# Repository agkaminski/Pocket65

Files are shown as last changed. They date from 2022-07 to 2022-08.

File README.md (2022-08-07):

# Pocket65

Handheld PC based on the original 6502 CPU that fits into a pocket.

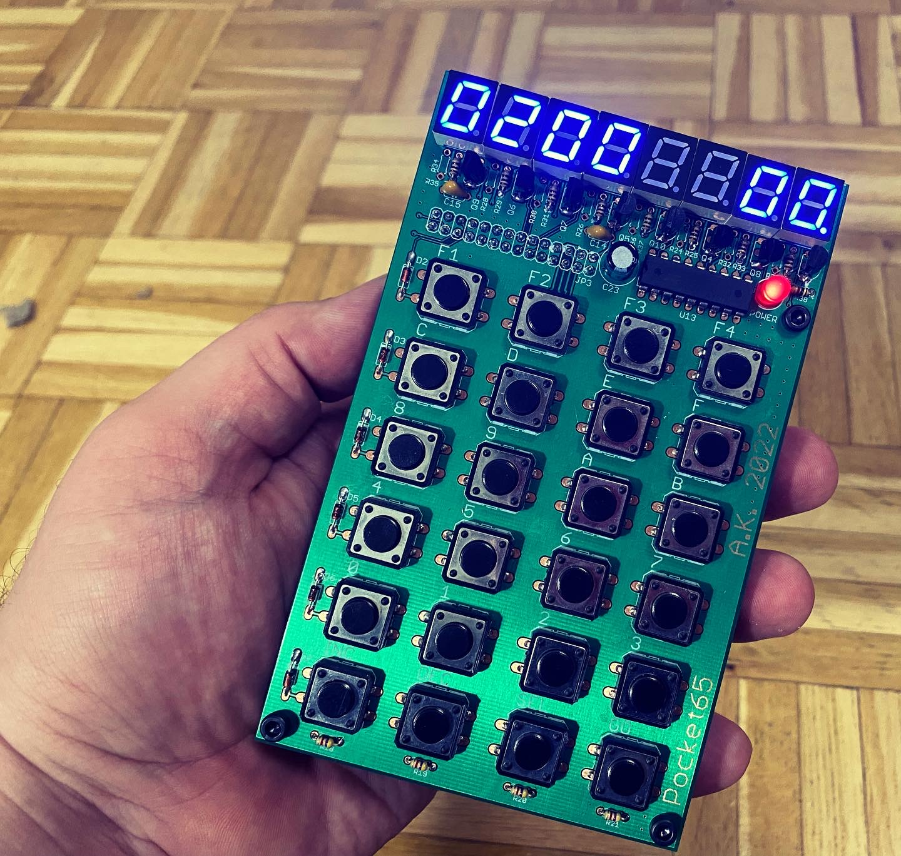
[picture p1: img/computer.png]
computer


## Features

- 8 digit multiplexed 7-segment display,
- 24 button keyboard,
- 2 KB of ROM and 2 KB of RAM,
- built-in Li-Po power supply and charger,
- monitor FW that allows memory edit and running user programs,
- expansion slot with 3 chip selects (up to 24 KB of external I/O and/or memory).

# Memory map

| Start  | End | Description |
|---|---|---|
| 0x0000 | 0x07FF | RAM |
| 0x0800 | 0x1FFF | RAM aliased |
| 0x2000 | 0x3FFF | External 1  |
| 0x4000 | 0x5FFF | External 2  |
| 0x6000 | 0x7FFF | External 3  |
| 0x8000 | 0x9FFF | Screen |
| 0xA000 | 0xBFFF | Keyboard |
| 0xC000 | 0xDFFF | NMI ack |
| 0xE000 | 0xF7FF | ROM aliased |
| 0xF800 | 0xFFFF | ROM |

# Monitor how-to

## Startup

First, welcome splash-screen is displayed:

welcome screen

After one second memory test result is displayed:

memory test result

On the right is a decimal number of RAM bytes found. By default it's 2048 bytes, memory can be expanded using expansion slot. If an error occurs during memory test, error screen is presented and the system is halted:

memory test fail

After 2 seconds computer proceeds to the main mode of operation:

monitor

## Memory edit

In the main mode and byte modification selected (dot near memory value) memory modification is possible. To modify memory press a key `0` to `F`. The old value is then shifted 4 binary places to the left and new nibble is inserted at the youngest position. Previous 4 oldest bits are lost.

Example - entering `0xBA` at current address:

We start with our memory cell selected (in this case at the address `0x0200`):

memory edit start

press `B` button to enter 0xB:

b pressed

then press `A` button to finish entering the byte:

a pressed

Done!

## Address selection

The address can be modified in two ways:

### INC/DEC buttons

To select next/prev memory cell press `INC`/`DEC` button. The address will be incremented/decremented by one.

### Entering new address

Big leaps through memory space are not very convenient using incrementation/decrementation. You can change the address very similar to changing memory value. To enter address edit mode pres `SEL` key. Dot will appear next to address to confirm mode selection:

address edit mode

In this mode address can be modified the same way memory value is performed - when key `0-F` is pressed the old address is shifted 4 bits to the left and new value is inserted at the youngest position.

To exit address edit mode (and return to the memory value edit mode) press `SEL` key.

## Executing user program

To start user program provides its entry point in the address field and press `GO` button.

## F1 key - auto increment mode

`F1` key toggles auto-increment mode. When on it's indicated by dots enabled next to both address and value:

autoincrement mode

When this mode is active when the whole byte is entered (i.e. two key `0-F` presses) address will be incremented automatically. This mode is very useful for binary program listing input, as no additional key press between bytes is needed.

## F2 key - memory clear

`F2` key clears user memory - sets it to all zeroes. Memory locations from `0x0000` to `0x000CF` and from `0x2000` to RAM end are cleared.

## F3 key - memory copy

`F3` key copies _length_ bytes from _source_ to _destination_. _Destination_ is selected as the current address. After pressing `F3` user is prompted for source address:

memcpy source

selection is confirmed with `GO` key. After that user is prompted for _length_:

memcpy length

selection is again confirmed with `GO` key. Memory is then copied and computer returns to the main screen.

## F4 key - jump to the external ROM

`F4` key allows for quick enter to the external ROM placed at address `0x6000` (external chip select #3). To detect if the external ROM is present monitor checks for a magic value at address `0x6000`. Expected value is `0x4B41` (little-endian). If this check is successful jump to external ROM at address `0x6002` is performed. Otherwise an error message is displayed:

error

# Programming

User program examples are provided in `fw/example` directory, along with user program template, BIOS calls user library and Makefile.

User is free to use all memory, exluding:

| Start  | End | Description |
|---|---|---|
| 0x00D0 | 0x00FF | ROM ZP area |
| 0x0100 | 0x01FF | HW stack |
| 0x8000 | 0xDFFF | HW handled by ROM |

## Interrupts

Interrupt vectors are located in ROM area, so they cannot be changed by application code. Monitor can handle user IRQ and NMI handlers - there are two system calls to register user interrupt handler

- `svc_irq_register` register the IRQ handler,
- `svc_nmi_register` register the NMI handler.

The handler address is passed in X (low byte) and Y (high byte) registers.

Use `RTS` instruction to return from the handler insted of `RTI` - monitor handles return from the interrupt part.

## System calls

### Convention

When X, Y registers are used to pass 16-bit value, X holds low byte and Y holds high byte.

### `svc_reset`

Perform warm reset.

- Arguments: none.
- Returns: none.
- Destroys: N/A.

### `svc_irq_register`

Register user IRQ handler and enables interrupts.

- Arguments: X, Y - handler address.
- Returns: none.
- Destroys: A.

### `svc_nmi_register`

Register user NMI handler.

- Arguments: X, Y - handler address.
- Returns: none.
- Destroys: A.

### `svc_get_screen_ptr`

Return a pointer to the screen frame buffer to allow direct screen manipulation.

- Arguments: nome.
- Returns: X, Y - address.
- Destroys: none.

### `svc_putch`

Displays hex character on the screen on position X.

- Arguments: A - character, X - position
- Returns: none.
- Destroys: Y.

### `svc_putbyte`

Display a hex byte on the screen on position X. X is incremented to point on the next free screen posion.

- Arguments: A - byte, X - position
- Returns: none.
- Destroys: none.

### `svc_dot_enable`

Enable dot on the position X.

- Arguments: X - position
- Returns: none.
- Destroys: A.

### `svc_dot_disable`

Disable dot on the position X.

- Arguments: X - position
- Returns: none.
- Destroys: A.

### `svc_clear_screen`

Clear screen.

- Arguments: none.
- Returns: none.
- Destroys: A, X.

### `svc_prinx_u16`

Print 16-bit number in registers X, Y as hexadecimal number justified to the right.

- Arguments: X, Y - number.
- Returns: none.
- Destroys: A, X.

### `svc_prind_u16`

Print 16-bit number in registers X, Y as unsigned decimal number justified to the right.

- Arguments: X, Y - number.
- Returns: none.
- Destroys: A, X, Y.

### `svc_prind_s16`

Print 16-bit number in registers X, Y as signed decimal number justified to the right.

- Arguments: X, Y - number.
- Returns: none.
- Destroys: A, X, Y.

### `svc_prind_s16`

Print NULL terminated decoded 7 segment string from position A.

- Arguments: X, Y - pointer to the string, A - position on the screen.
- Returns: none.
- Destroys: A, X, Y.

### `svc_scanx_u16`

Get 16-bit unsigned number from the user (hexadecimal input).

- Arguments: none.
- Returns: X, Y - number.
- Destroys: A, X, Y.

### `svc_scand_u16`

Get 16-bit unsigned number from the user (decimal input).

- Arguments: none.
- Returns: X, Y - number.
- Destroys: A, X, Y.

### `svc_get_key`

Get key code - block until new key is pressed.

- Arguments: none.
- Returns: A - key code.
- Destroys: none.

### `svc_get_key_nb`

Get current key code.

- Arguments: none.
- Returns: A - key code.
- Destroys: none.

### `svc_get_jiffies`

Get current miliseconds value (one byte).

- Arguments: none.
- Returns: A - jiffies.
- Destroys: none.

### `svc_get_seconds`

Get current seconds value (one byte).

- Arguments: none.
- Returns: A - seconds.
- Destroys: none.

### `svc_msleep`

Sleep for 0-255 ms.

- Arguments: A - time (ms).
- Returns: none.
- Destroys: A.

### `svc_sleep`

Sleep for 0-255 s.

- Arguments: A - time (s).
- Returns: none.
- Destroys: A.

# License

Free for non-commercial use and educational purposes. See LICENSE.md for details.

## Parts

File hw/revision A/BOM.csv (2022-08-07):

Qty | Value | Device | Package | Parts | Description | MF | MPN | OC_FARNELL | OC_NEWARK | TP_SIGNAL_NAME
24 |  | 40-XX | B3F-40XX | 0, 1, 2, 3, 4, 5, 6, 7, 8, 9, A, B, C, D, DEC, E, F, F1, F2, F3, F4, GO, INC, SEL | OMRON SWITCH | OMRON COMPONENTS USA | B3F-4000 | 176434 | 36K3105
3 |  | CPOL-EUE3.5-8 | E3,5-8 | C22, C23, C24 | POLARIZED CAPACITOR, European symbol
1 |  | DIP-TOGGLE-SWITCH-2CH-(2X3P-2.54-90D)'90D' | SW6-2.54-9.0X3.5X3.2MM-90D | SW1 | 311030004
1 |  | L-EUL4532P | L4532P | L1 | INDUCTOR, European symbol
1 |  | LED5MM | LED5MM | POWER | LED
2 |  | PINHD-2X14 | 2X14 | JP1, JP3 | PIN HEADER
1 |  | PINHD-2X16/90 | 2X16/90 | JP2 | PIN HEADER
3 |  | SJ | SJ | SJ1, SJ2, SJ3 | SMD solder JUMPER
1 |  | ULN2803A | DIL18 | U13 | DRIVER ARRAY
1 | 10-50p | C-TRIMM3050.504 | CTRIM3050.504 | C2 | Trimm capacitor
1 | 100K | R-EU_0204/5 | 0204/5 | R13 | RESISTOR, European symbol
9 | 100R | R-EU_0204/5 | 0204/5 | R7, R23, R25, R27, R29, R31, R33, R35, R37 | RESISTOR, European symbol
14 | 100n | C-EU050-024X044 | C050-024X044 | C4, C5, C6, C7, C8, C9, C10, C11, C12, C13, C14, C15, C16, C17 | CAPACITOR, European symbol
2 | 100n | C-EUC0805K | C0805K | C18, C20 | CAPACITOR, European symbol
5 | 10K | R-EU_0204/5 | 0204/5 | R12, R14, R15, R16, R17 | RESISTOR, European symbol
1 | 10K | RN08 | RN-9 | RN1 | RESISTOR NETWORK |  |  | unknown | unknown
1 | 10p | C-EU025-025X050 | C025-025X050 | C1 | CAPACITOR, European symbol
1 | 1K | R-EU_0204/5 | 0204/5 | R38 | RESISTOR, European symbol
1 | 1K | R-EU_R0805 | R0805 | R40 | RESISTOR, European symbol
1 | 1MHz | QG5860 | DIL14S | QG1 | CRYSTAL RESONATOR |  |  | unknown | unknown
7 | 1N4148 | 1N4148DO35-7 | DO35-7 | D1, D2, D3, D4, D5, D6, D7 | DIODE
1 | 1u | CPOL-EUE2-5 | E2-5 | C3 | POLARIZED CAPACITOR, European symbol
4 | 220R | R-EU_0204/5 | 0204/5 | R8, R9, R10, R11 | RESISTOR, European symbol
1 | 2716 | 2716 | DIL24 | U2 | MEMORY
1 | 32K | CRYSTALTC26H | TC26H | Q1 | CRYSTAL |  |  | unknown | unknown
1 | 330K | R-EU_0204/5 | 0204/5 | R5 | RESISTOR, European symbol
1 | 4060N | 4060N | DIL16 | U6 | 14-stage binary/ripple COUNTER
1 | 470R | R-EU_R0805 | R0805 | R39 | RESISTOR, European symbol
4 | 4K7 | R-EU_0204/5 | 0204/5 | R18, R19, R20, R21 | RESISTOR, European symbol
2 | 4u7 | C-EUC0805K | C0805K | C19, C21 | CAPACITOR, European symbol
3 | 5M1 | R-EU_0204/5 | 0204/5 | R1, R2, R3 | RESISTOR, European symbol
1 | 6502_CPU | 6502_CPU | DIL40 | U1
1 | 6K8 | R-EU_R0805 | R0805 | R41 | RESISTOR, European symbol
1 | 74HC138N | 74HC138N | DIL16 | U4 | 3-line to 8-line DECODER/DEMULTIPLEXER
1 | 74HC14N | 74HC14N | DIL14 | U5 | Hex schmitt trigger INVERTER
2 | 74HC244N | 74HC244N | DIL20 | U8, U9 | Octal BUFFER and LINE DRIVER, 3-state
1 | 74HC245N | 74HC245N | DIL20 | U10 | Octal BUS TRANSCEIVER, 3-state
2 | 74HC373N | 74HC373N | DIL20 | U11, U12 | Octal D type transparent LATCH, edge triggered
1 | 74HC74N | 74HC74N | DIL14 | U7 | Dual D type positive edge triggered FLIP FLOP, preset and clear
1 | BC547 | BC547 | TO92 | Q2 | NPN Transistor
8 | BC547 | BC547-NPN-TO92-CBE | TO92-CBE | T1, T2, T3, T4, T5, T6, T7, T8 | NPN Transistror
1 | CDM6118 | 6116P | DIL24-6 | U3 | MEMORY |  |  | unknown | unknown
10 | DNP | R-EU_0204/5 | 0204/5 | R4, R6, R22, R24, R26, R28, R30, R32, R34, R36 | RESISTOR, European symbol
1 | MICRO_USB_LIPO_MODULE | MICRO_USB_LIPO_MODULE | MICRO_USB_LIPO_MODULE | U14
2 | PAD-0595 | PAD-0595 | 0595 | BAT+, BAT- | WIRE PAD
8 | S4301B | S4301B | S4301B | LED1, LED2, LED3, LED4, LED5, LED6, LED7, LED8 | Single Digit Seven-Segment Display (cathode common) |  |  | unknown | unknown
1 | SS31 | SCHOTTKY-DIODESMD | SMB | D8 | Schottky Diode
1 | SW_TACT_4P_B | SW_TACT_4P_B | SW_TACT_STANDARD_RIGHT_ANGLE | RESET
1 | SX1308 | SX1308 | SOT23-6 | U15
8 | TPB1,27 | TPB1,27 | B1,27 | TP1, TP2, TP3, TP4, TP5, TP6, TP7, TP8 | Test pad

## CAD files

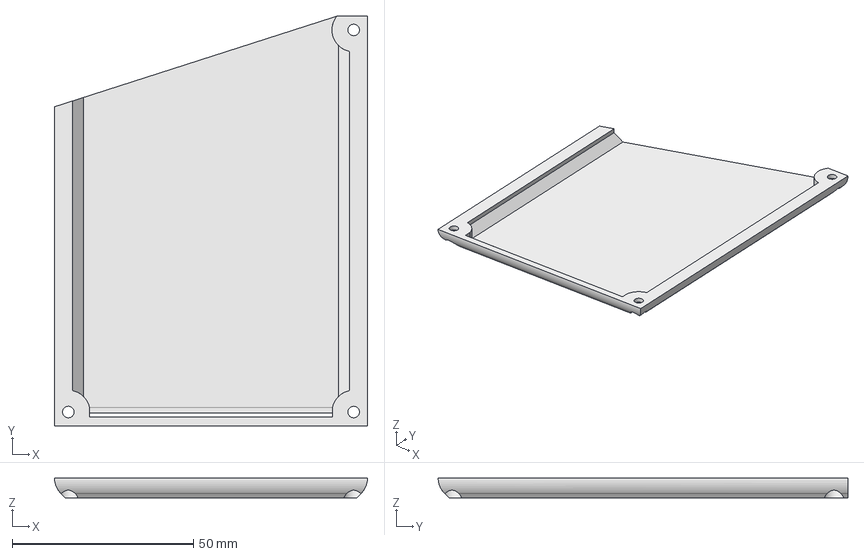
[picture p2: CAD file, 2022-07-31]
hw/3dprint/cover.FCStd
86.4 x 113.0 x 5.50 mm

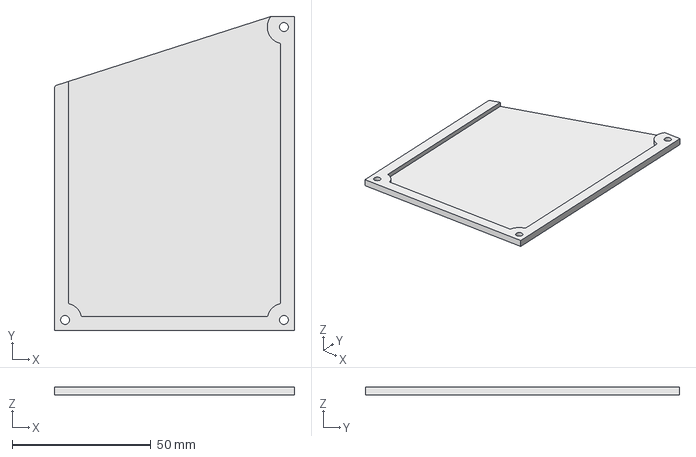
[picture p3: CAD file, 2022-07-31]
hw/3dprint/protector.FCStd
86.4 x 113.0 x 3.00 mm

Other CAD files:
hw/3dprint/cover.stl
hw/3dprint/protector.stl

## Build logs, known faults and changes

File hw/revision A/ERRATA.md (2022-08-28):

# Errata to Pocket65 v1 rev A

Hardware bugs found first prototype assembly

## Wrong USB battery charger footprint

USB charger module footprint is wrong, especially the pads for battery connection. These pads overlap power output pads.

### Solution

USB charger module needs to be mounted with some separation from the computer PCB. 1-pin goldpin headers with standard 0.1'' standoff placed in each corner do an excellent job. Then the battery connection can be connected too using a wire (e.g. left-over leads of a THT resistor).

## Top/bottom PCB collision

Top PCB button leads on the bottom side collide with various elements on the bottom PCB - capacitors, integrated circuits in sockets etc.

### Solution

Trim all button leads, so they don't poke out from the bottom of top PCB.

## Expansion connector sticks out too much

During the design phase it was supposed to be male connector, later changed to female connector, which does not need any stick-out.

### Solution

None needed, but should be fixed in future revisions.

## Memory timing issues

Some 2716 chips dont work right - computer crashes. About half of my stock 2716 works, other half does not.

### Solution

None, if computer crashes replace EPROM with another 2716.

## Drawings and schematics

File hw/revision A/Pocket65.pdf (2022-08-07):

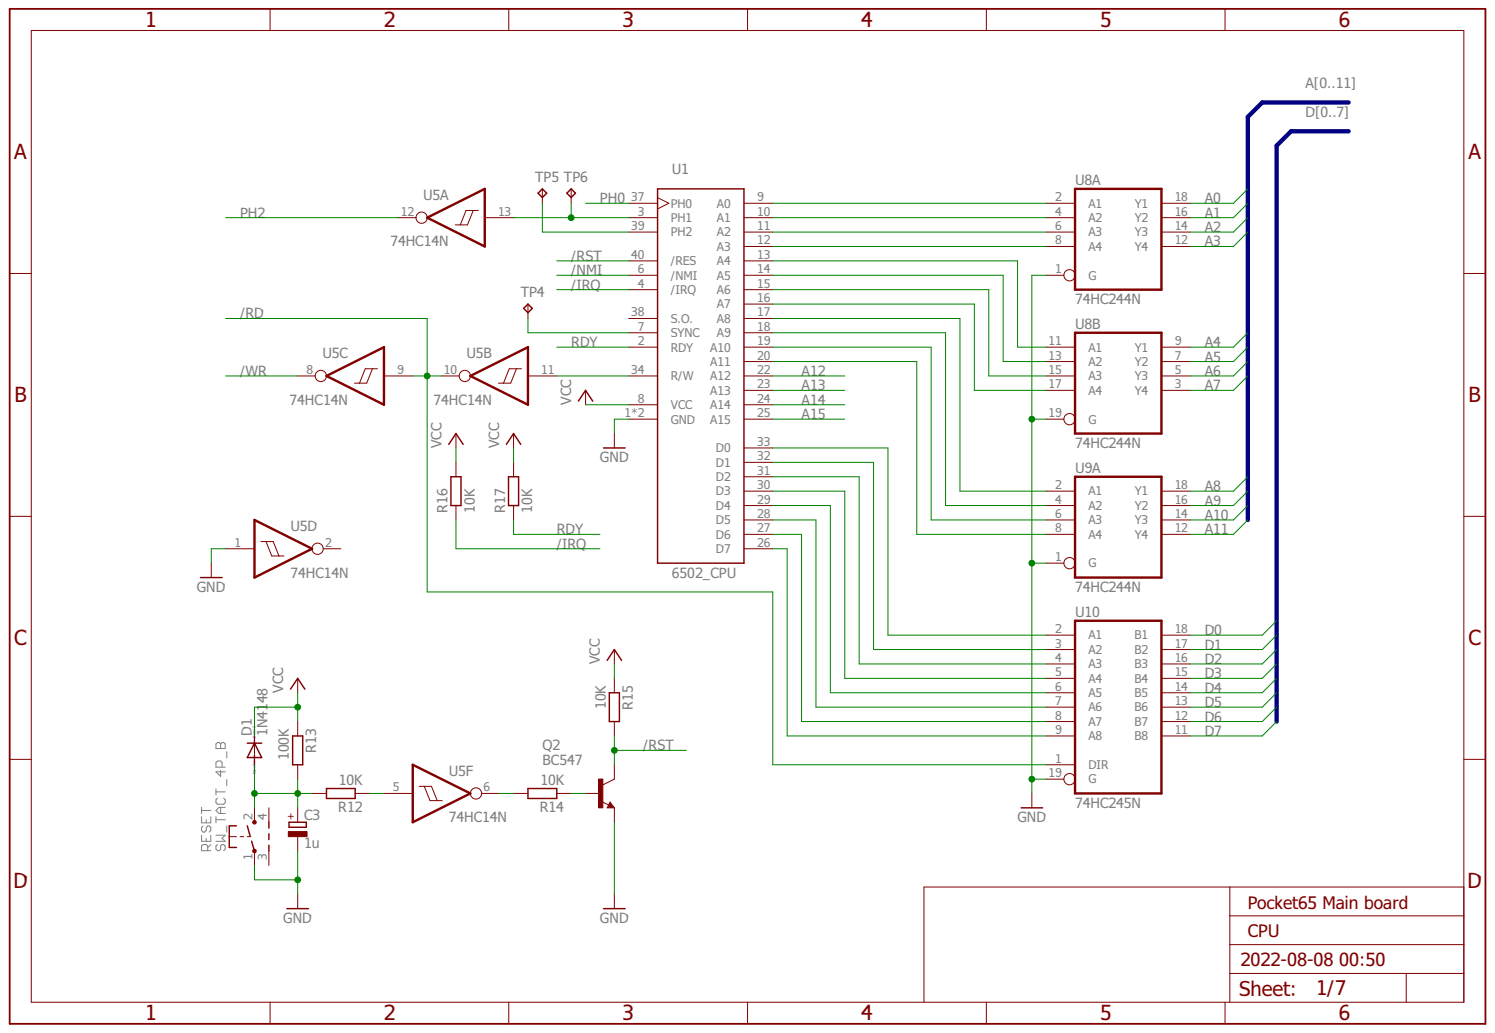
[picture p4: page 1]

SpiceOrder 1 SpiceOrder 2 VCC GND 74HC245N 74HC244N 74HC244N 74HC244N GND 74HC14N 74HC14N 74HC14N 74HC14N 74HC14N 10K 100K GND1u VCC 1N4148 BC547 10K 10K VCC GND 10K 10K VCC VCC GND PH0 37 PH1 3 PH2 39 /RES 40 /NMI 6 /IRQ 4 S.O. 38 SYNC 7 RDY 2 R/W 34 VCC 8 GND 1*2 A0 9 A1 10 A2 11 A3 12 A4 13 A5 14 A6 15 A7 16 A8 17 A9 18 A10 19 A11 20 A12 22 A13 23 A14 24 A15 25 D0 33 D1 32 D2 31 D3 30 D4 29 D5 28 D6 27 D7 26 U16502_CPU U10DIR 1 A1 2 A2 3 A3 4 A4 5 A5 6 A6 7 A7 8 A8 9 B8 11 B7 12 B6 13 B5 14 B4 15 B3 16 B2 17 B1 18 G 19 U8AG 1 A1 2 A2 4 A3 6 A4 8 Y4 12 Y3 14 Y2 16 Y1 18 U8BG 19 A1 11 A2 13 A3 15 A4 17 Y4 3 Y3 5 Y2 7 Y1 9 U9AG 1 A1 2 A2 4 A3 6 A4 8 Y4 12 Y3 14 Y2 16 Y1 18 TP4TP5 TP6 U5A 12 13 U5B 10 11 U5C 8 9 U5D 1 2 U5F 5 6 R12 R13 C3 D1 1 24 3 Q2 R14 R15 R16 R17 A[0..11] D[0..7] /RD A0A1A2A3A4A5A6A7A8A9A10 A13 A14 A15 D0D1D2D3D4D5D6D7 /NMI /IRQ /IRQ/RST /RST PH2 A11 RDY RDY PH0 /WR A12 CPU Pocket65 Main board + Sheet: ABCD 1 2 3 4 5 6 ABCD 1 2 3 4 5 6 2022-08-08 00:50 1/7

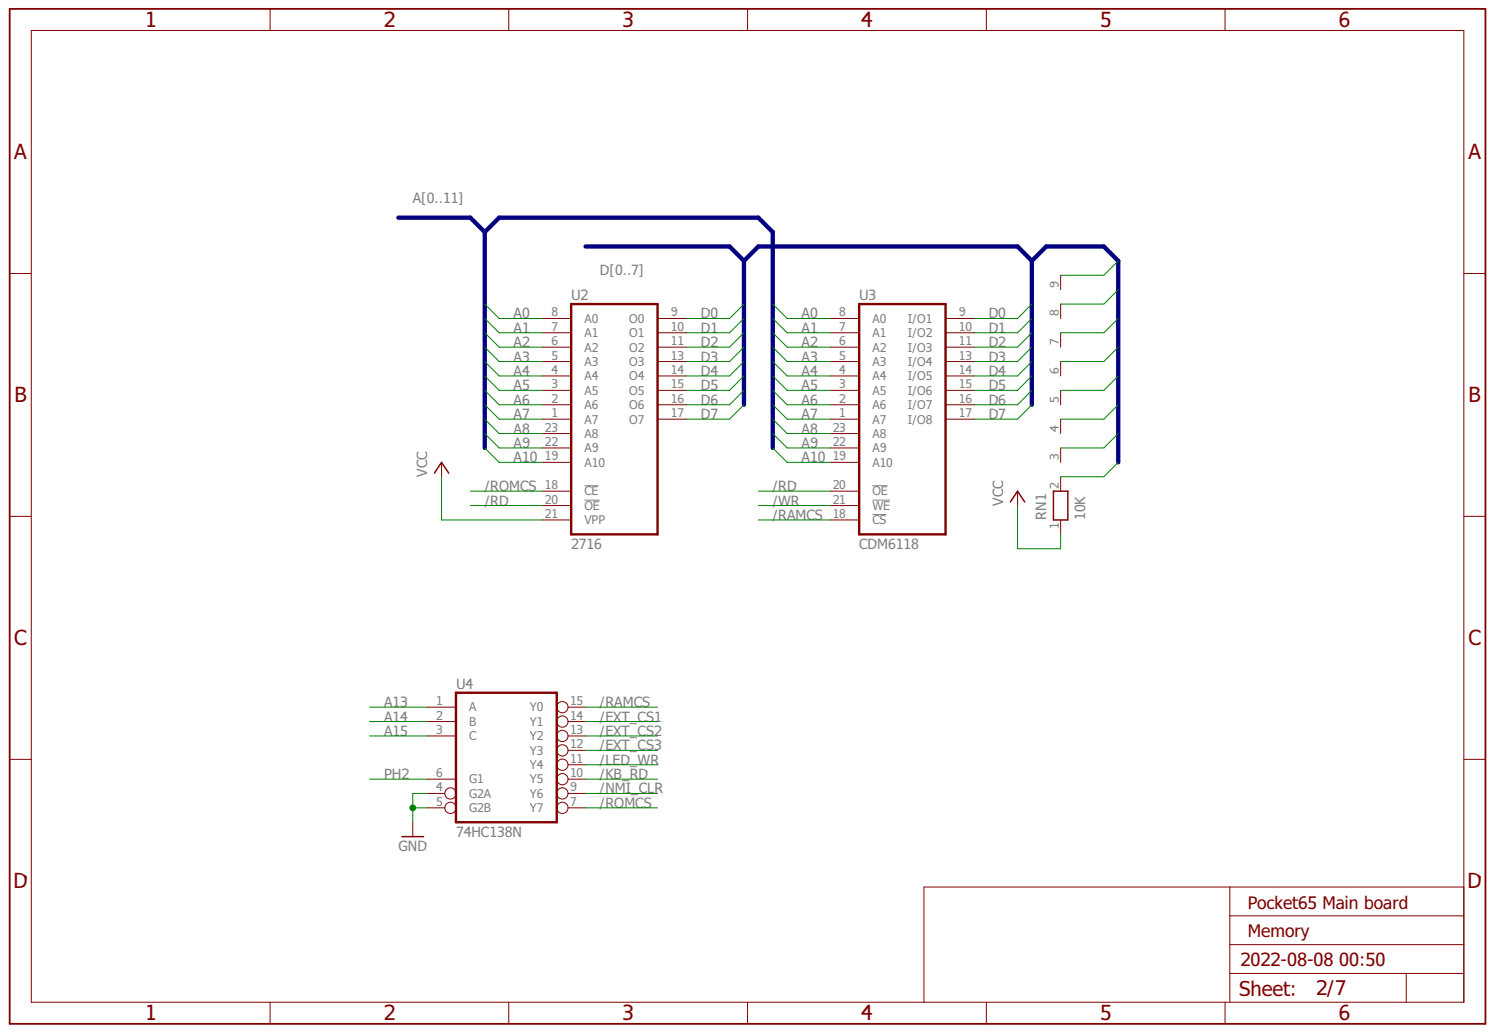
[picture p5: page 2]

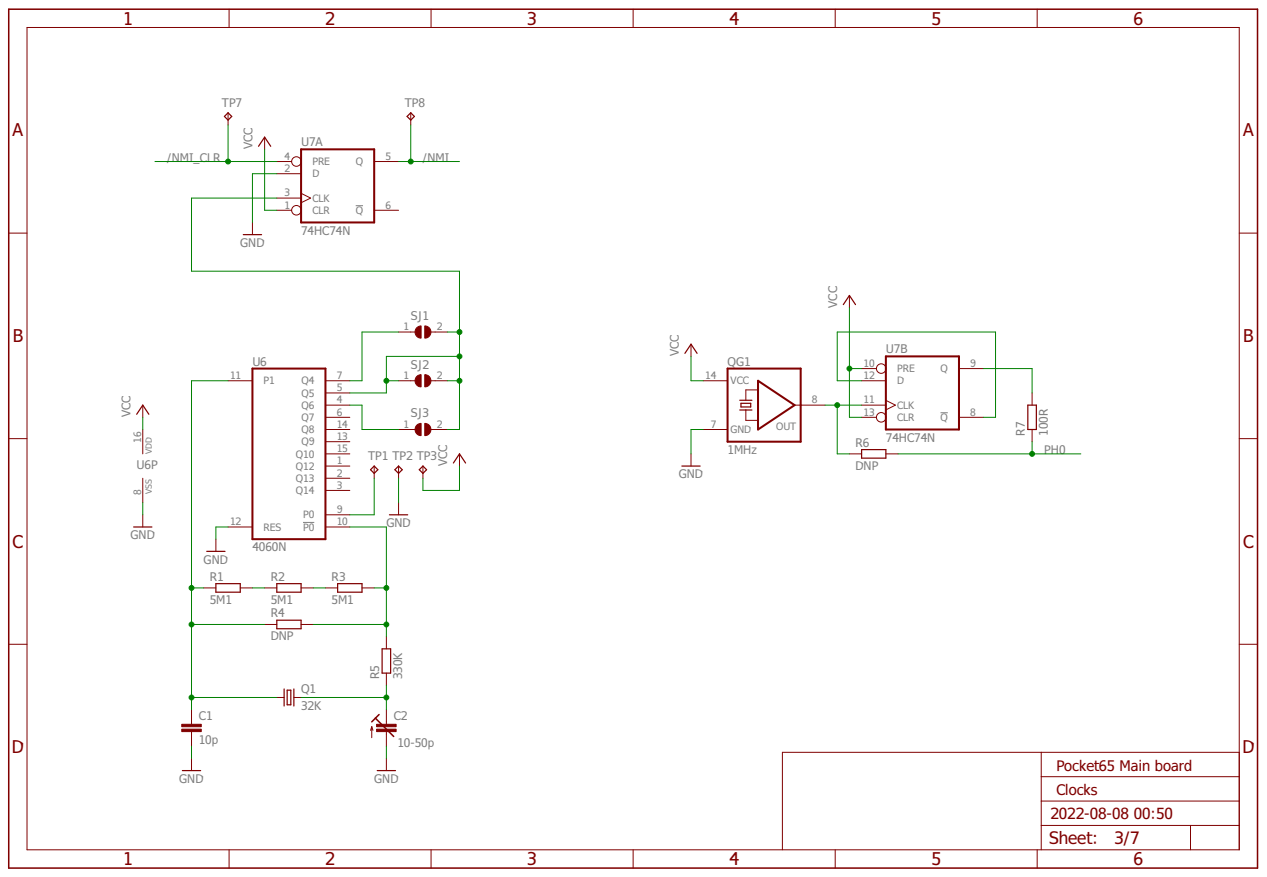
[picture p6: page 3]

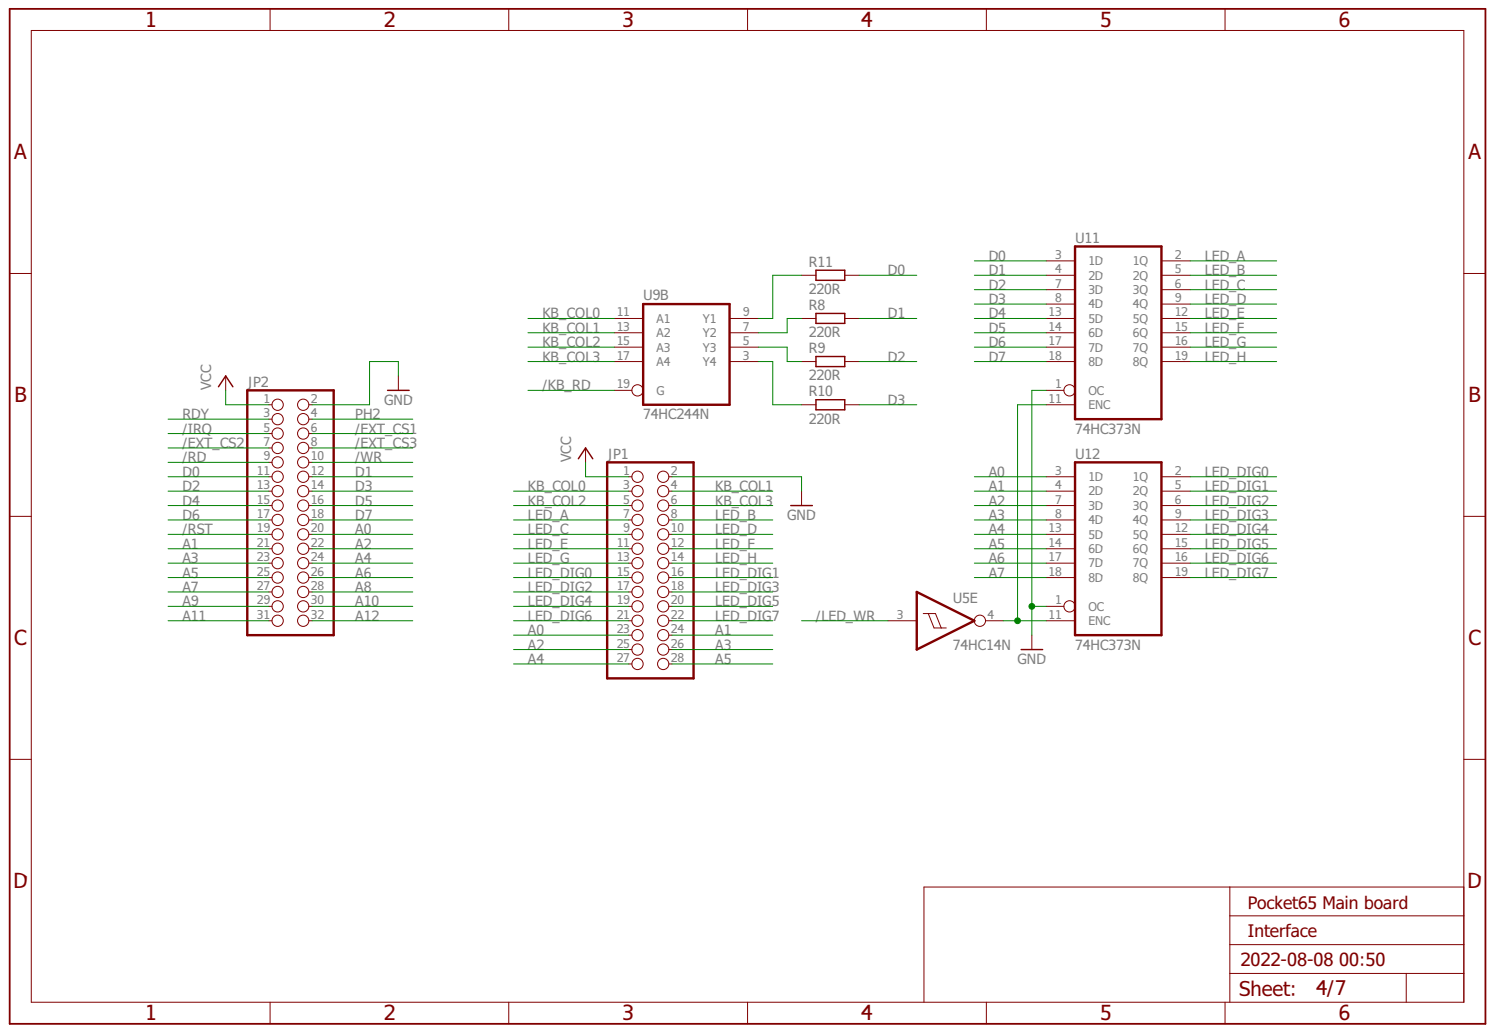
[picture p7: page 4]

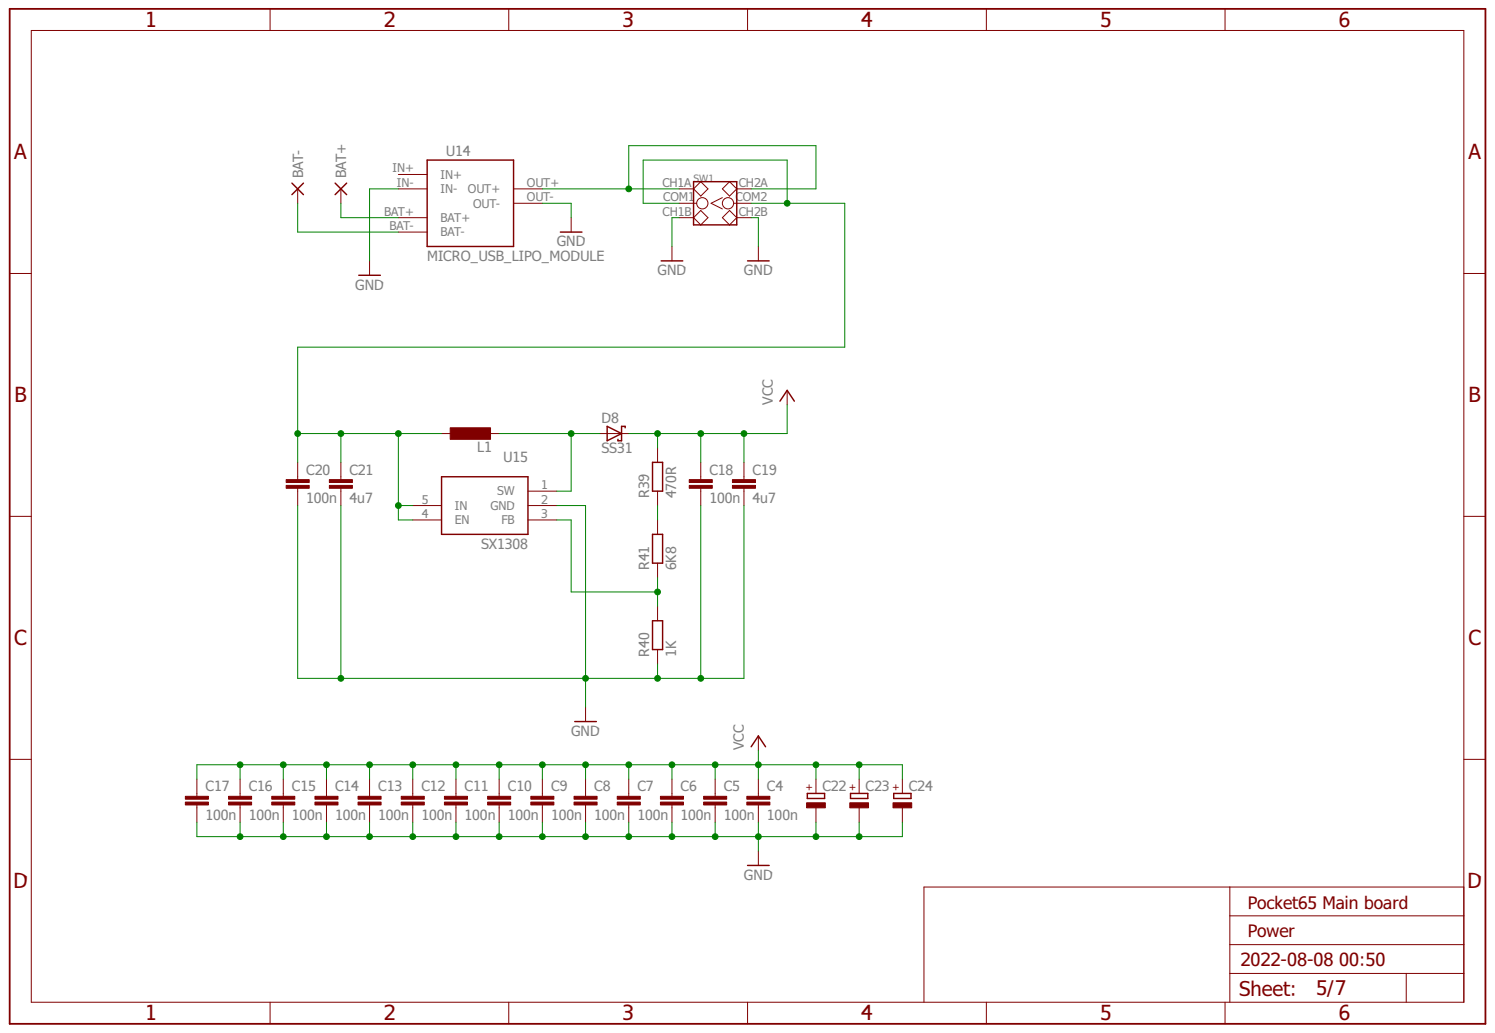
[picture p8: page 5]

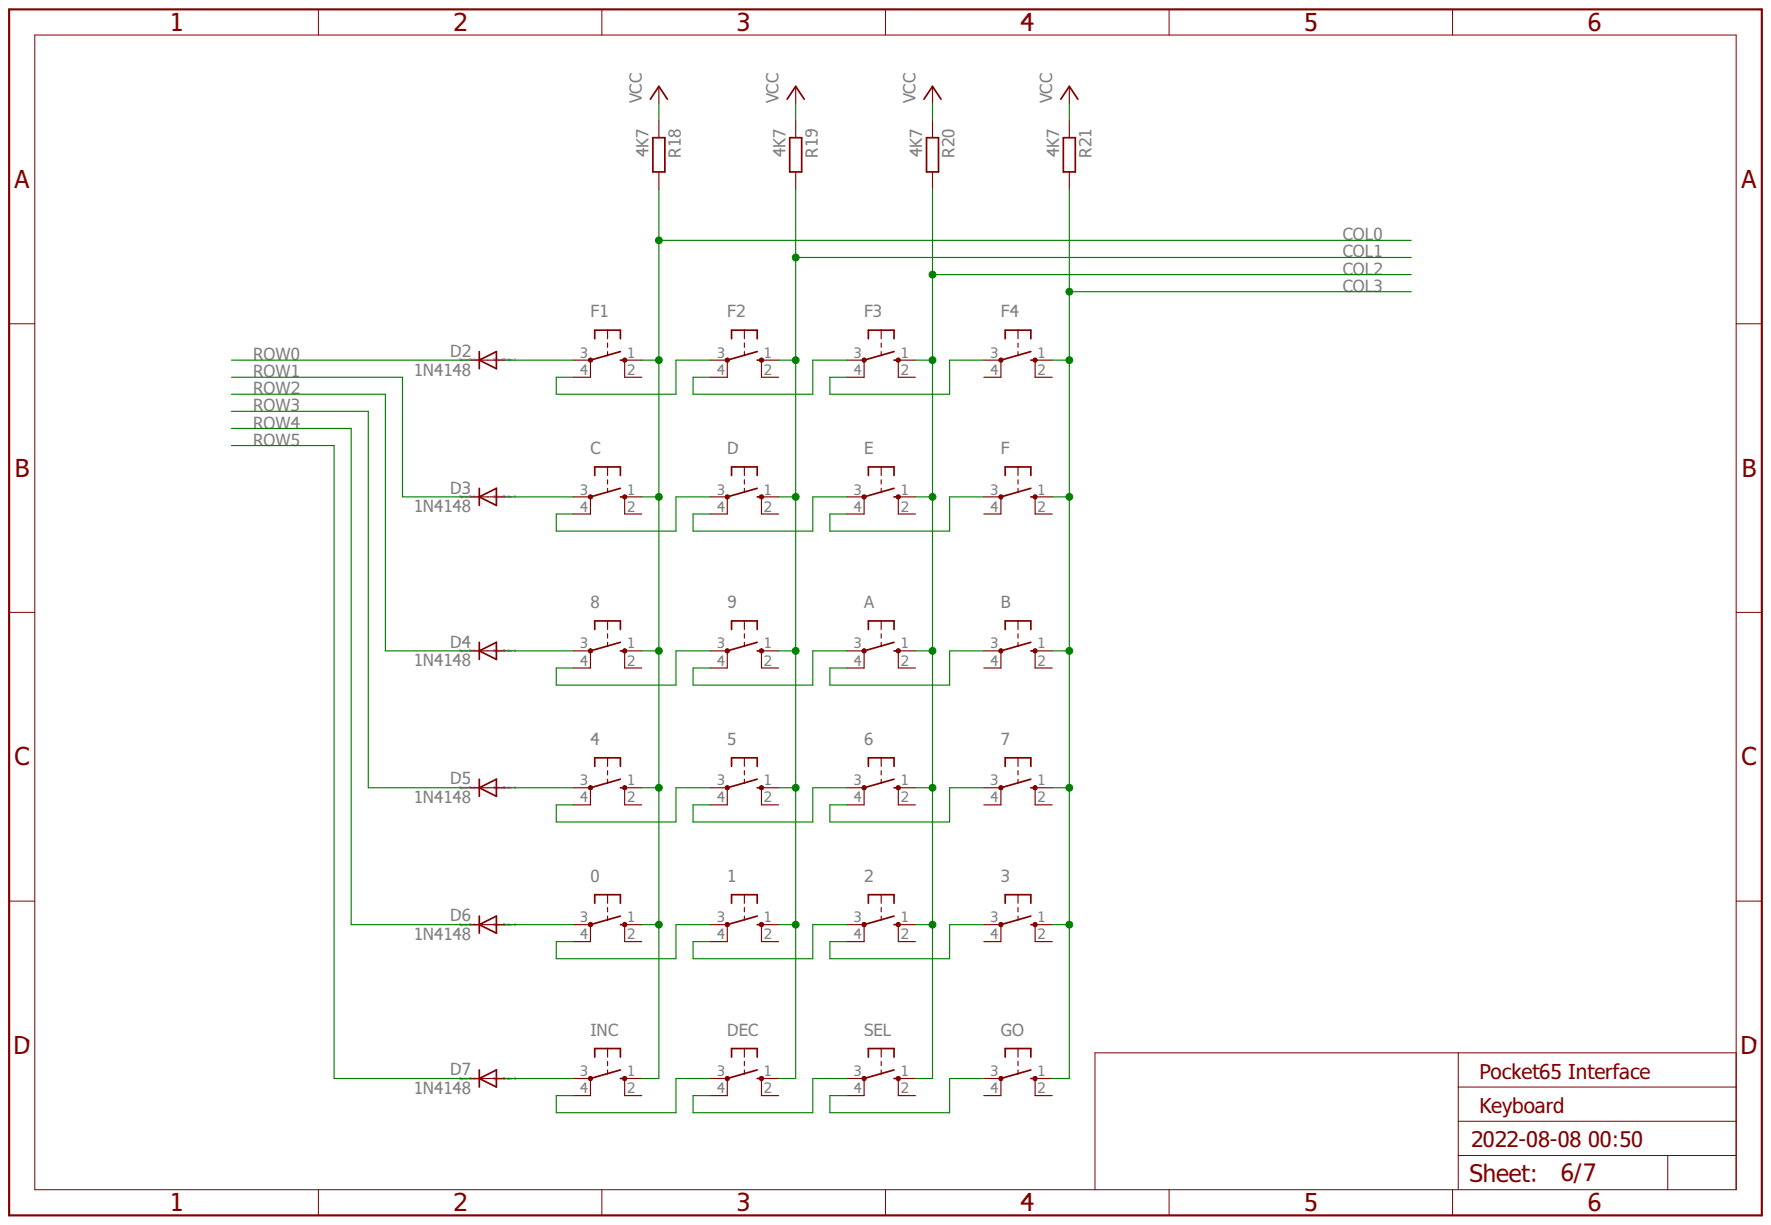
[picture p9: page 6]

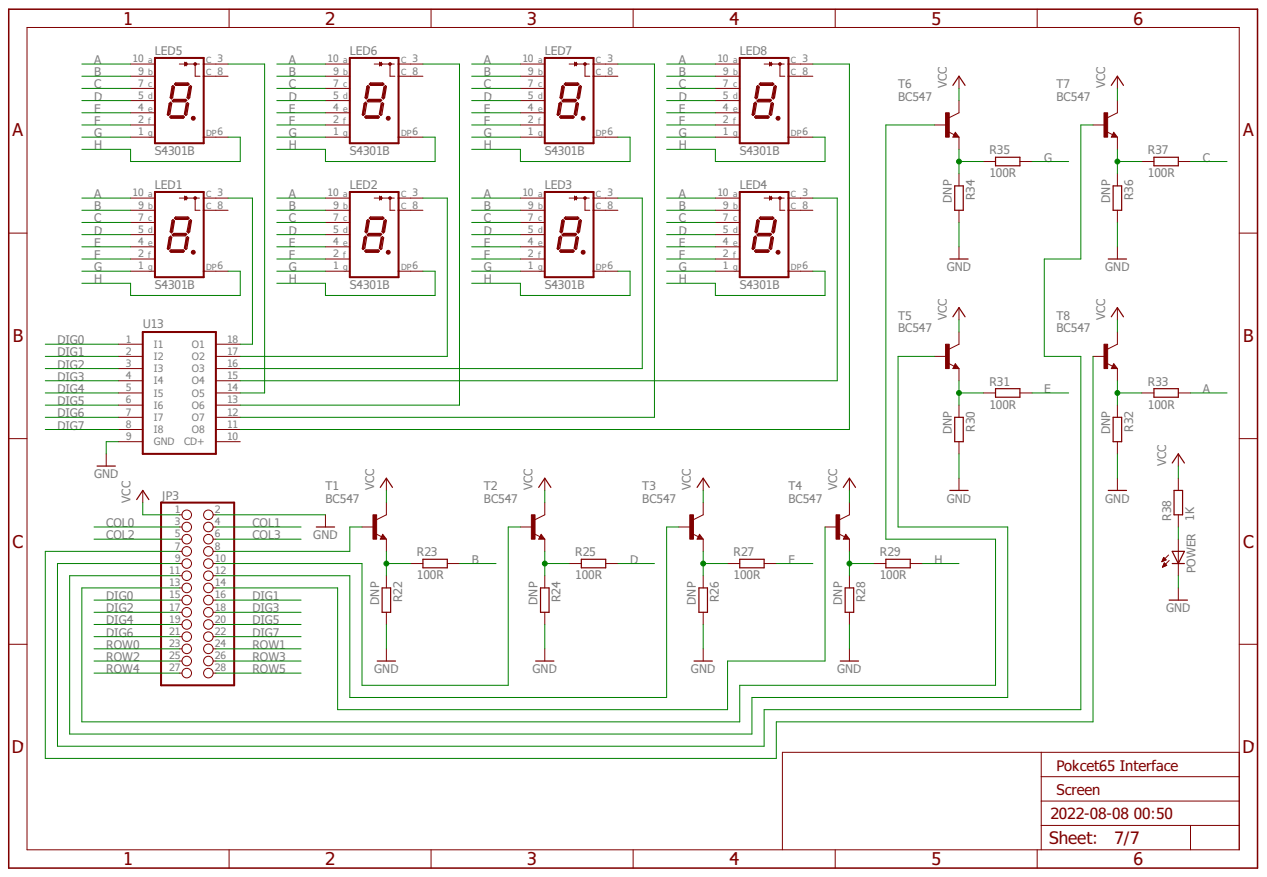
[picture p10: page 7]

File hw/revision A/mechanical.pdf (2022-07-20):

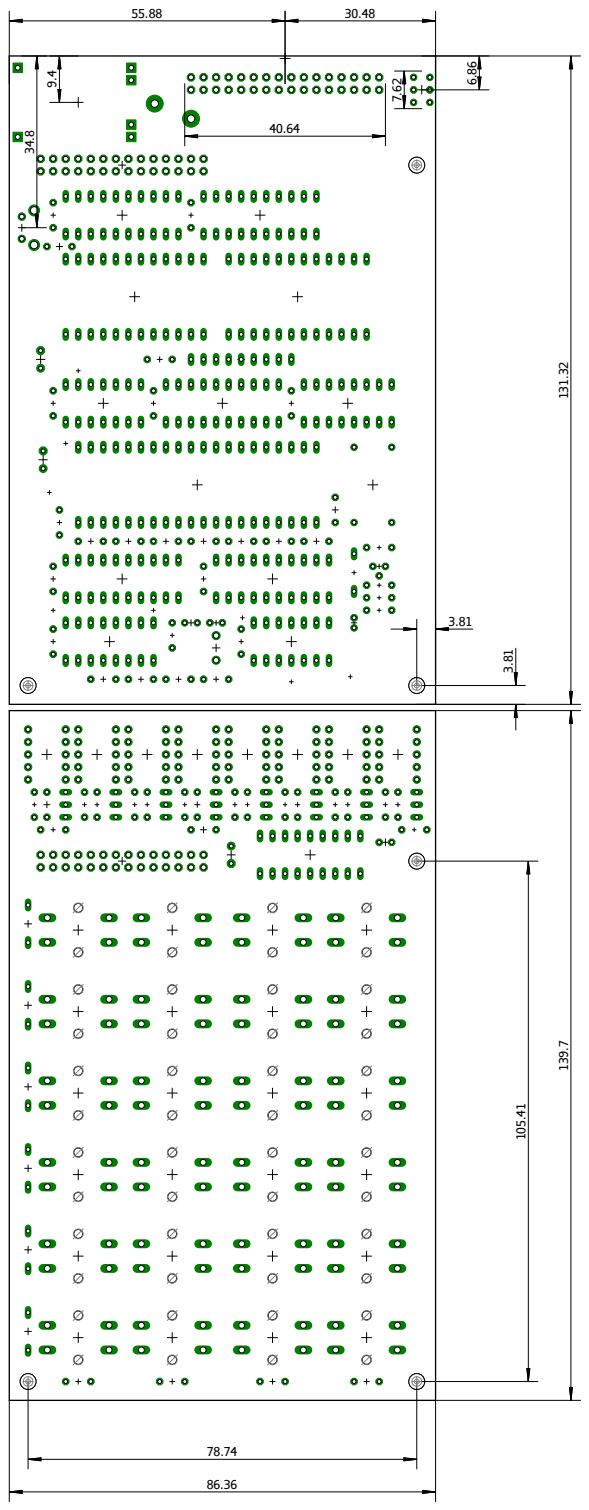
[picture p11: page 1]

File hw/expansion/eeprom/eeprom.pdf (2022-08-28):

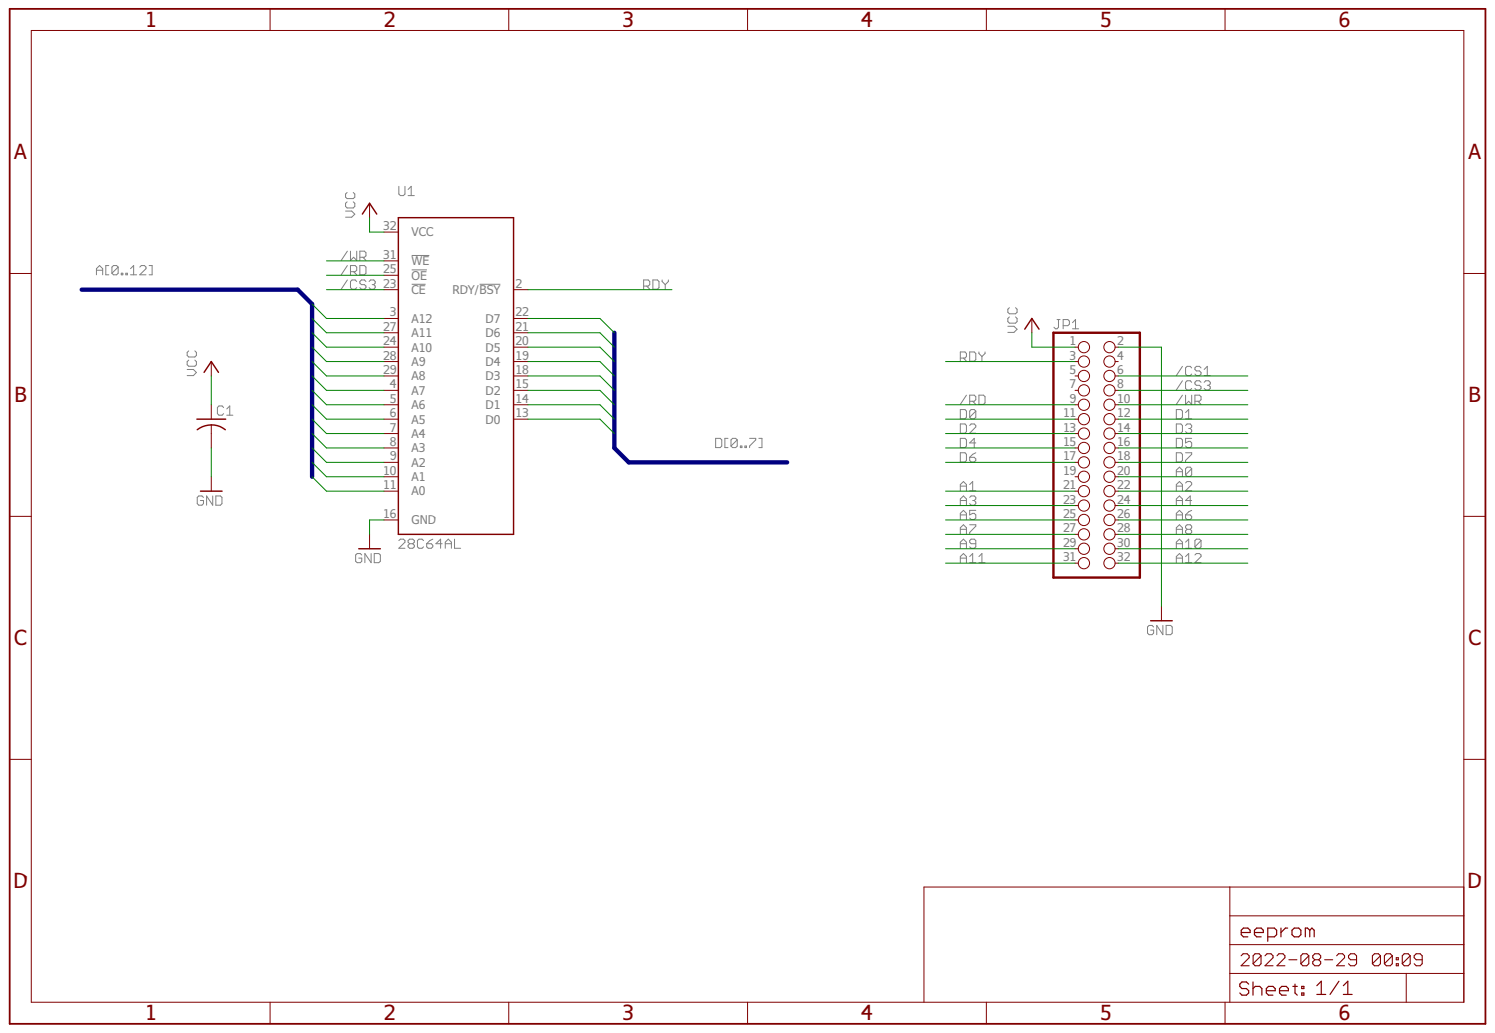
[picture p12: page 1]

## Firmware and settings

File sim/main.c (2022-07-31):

#include <stdio.h>
#include <stdlib.h>
#include <string.h>
#include <unistd.h>
#include <ctype.h>
#include <termios.h>
#include <unistd.h>
#include "common/threads.h"
#include "common/error.h"
#include "core/core.h"
#include "parser/parser.h"
#include "bus/memory.h"
#include "bus/bus.h"

#define DEFAULT_FREQ 1000000

void usage(char *progname)
{
	printf("Usage: %s [options]\n", progname);
	printf("Options:\n");
	printf("  -f <file>    Initialize RAM with intel hex, srec or binary file.\n");
	printf("  -o <offset>  Put data from file begging at offet <offset>.\n");
	printf("  -s <freq>    Set core clock frequency to <freq> Hz (default 1 MHz)\n");
	printf("  -h           This help.\n");
}


u8 screen[8];
u8 key_row[6];


void screen_write(u16 addr, u8 data)
{
	u16 i;

	DEBUG("screen write @%04x = %02x\n", addr, data);

	for (i = 0; i < 8; ++i) {
		if (addr & (1 << i)) {
			screen[i] = data;
		}
	}
}


u8 screen_read(u16 addr)
{
	return 0xff;
}


void keyboard_write(u16 addr, u8 data)
{
}


u8 keyboard_read(u16 addr)
{
	u16 i;
	u8 ret = 0xff;

	for (i = 0; i < 6; ++i) {
		if (!((1 << i) & addr)) {
			ret = key_row[i] | 0xf0;
		}
	}

	DEBUG("%04x %02x\n", addr, ret);

	return ret;
}


void *keyboard_thread(void *arg)
{
	int c, pressed;

	static struct termios oldt, newt;

	tcgetattr(STDIN_FILENO, &oldt);
	newt = oldt;
	newt.c_lflag &= ~(ICANON);
	tcsetattr(STDIN_FILENO, TCSANOW, &newt);

	while (1) {
		c = getchar();

		if (isalpha(c))
			c = tolower(c);

		pressed = 1;

		switch (c) {
			case '0': key_row[4] = 0xfe; break;
			case '1': key_row[4] = 0xfd; break;
			case '2': key_row[4] = 0xfb; break;
			case '3': key_row[4] = 0xf7; break;

			case '4': key_row[3] = 0xfe; break;
			case '5': key_row[3] = 0xfd; break;
			case '6': key_row[3] = 0xfb; break;
			case '7': key_row[3] = 0xf7; break;

			case '8': key_row[2] = 0xfe; break;
			case '9': key_row[2] = 0xfd; break;
			case 'a': key_row[2] = 0xfb; break;
			case 'b': key_row[2] = 0xf7; break;

			case 'c': key_row[1] = 0xfe; break;
			case 'd': key_row[1] = 0xfd; break;
			case 'e': key_row[1] = 0xfb; break;
			case 'f': key_row[1] = 0xf7; break;

			case 'h': key_row[5] = 0xfe; break; /* INC */
			case 'j': key_row[5] = 0xfd; break; /* DEC */
			case 'k': key_row[5] = 0xfb; break; /* SEL */
			case 'l': key_row[5] = 0xf7; break; /* GO */

			case 'u': key_row[0] = 0xfe; break; /* F1 */
			case 'i': key_row[0] = 0xfd; break; /* F2 */
			case 'o': key_row[0] = 0xfb; break; /* F3 */
			case 'p': key_row[0] = 0xf7; break; /* F4 */
			default:  pressed = 0; break;
		}

		if (pressed) {
			usleep(100 * 1000);
			memset(key_row, 0xff, sizeof(key_row));
		}
	}

	tcsetattr(STDIN_FILENO, TCSANOW, &oldt);
}



void pocket65(void)
{
	int i;
	char cscreen[17];
	busentry_t busentry;
	thread_t keyb_thread;

	memset(key_row, 0xff, sizeof(key_row));

	/* screen */
	busentry.begin = 0x8000;
	busentry.end = 0x9fff;
	busentry.write = screen_write;
	busentry.read = screen_read;

	bus_register(busentry);

	/* keyboard */
	busentry.begin = 0xa000;
	busentry.end = 0xbfff;
	busentry.write = keyboard_write;
	busentry.read = keyboard_read;

	bus_register(busentry);

	core_run();

	thread_create(&keyb_thread, keyboard_thread, NULL);

	while (1) {
		for (i = 0; i < 8; ++i) {
			switch (screen[i] & 0x7F) {
				case 0x3F: cscreen[i * 2] = '0'; break;
				case 0x06: cscreen[i * 2] = '1'; break;
				case 0x5B: cscreen[i * 2] = '2'; break;
				case 0x4F: cscreen[i * 2] = '3'; break;
				case 0x66: cscreen[i * 2] = '4'; break;
				case 0x6D: cscreen[i * 2] = '5'; break;
				case 0x7D: cscreen[i * 2] = '6'; break;
				case 0x07: cscreen[i * 2] = '7'; break;
				case 0x7F: cscreen[i * 2] = '8'; break;
				case 0x6F: cscreen[i * 2] = '9'; break;
				case 0x77: cscreen[i * 2] = 'A'; break;
				case 0x7C: cscreen[i * 2] = 'B'; break;
				case 0x39: cscreen[i * 2] = 'C'; break;
				case 0x5E: cscreen[i * 2] = 'D'; break;
				case 0x79: cscreen[i * 2] = 'E'; break;
				case 0x71: cscreen[i * 2] = 'F'; break;
				case 0x40: cscreen[i * 2] = '-'; break;
				case 0x76: cscreen[i * 2] = 'H'; break;
				case 0x38: cscreen[i * 2] = 'L'; break;
				case 0x3e: cscreen[i * 2] = 'U'; break;
				case 0x54: cscreen[i * 2] = 'n'; break;
				case 0x73: cscreen[i * 2] = 'P'; break;
				case 0x50: cscreen[i * 2] = 'r'; break;
				default:   cscreen[i * 2] = ' '; break;
			}

			cscreen[i * 2 + 1] = (screen[i] & 0x80) ? '.' : ' ';
		}

		cscreen[sizeof(cscreen) - 1] = '\0';

		printf("\033[2J\x1B[H[ %s]\n\n"
		       "[ F1  ][ F2  ][ F3  ][ F4  ]\n"
		       "[ C   ][ D   ][ E   ][ F   ]\n"
		       "[ 8   ][ 9   ][ A   ][ B   ]\n"
		       "[ 4   ][ 5   ][ 6   ][ 7   ]\n"
		       "[ 0   ][ 1   ][ 2   ][ 3   ]\n"
		       "[ INC ][ DEC ][ SEL ][ GO  ]\n", cscreen);

		usleep(1 * 1000);
		core_nmi();
	}
}


int main(int argc, char *argv[])
{
	cycles_t cycles;
	u16 offset = 0;
	u8 *rom = NULL;
	char path[128];
	int c;
	int freq = DEFAULT_FREQ;

	memset(path, '\0', sizeof(path));

	while ((c = getopt(argc, argv, "o:f:s:hv")) != -1) {
		switch (c) {
			case 'o':
				offset = strtol(optarg, NULL, 0);
				break;

			case 'f':
				strncpy(path, optarg, sizeof(path) - 1);
				path[sizeof(path) - 1] = '\0';
				break;

			case 's':
				freq = strtol(optarg, NULL, 10);
				if (freq == 0) {
					WARN("Invalid frequency. Falling back to default.");
					freq = DEFAULT_FREQ;
				}
				break;

			case 'h':
				printf("AK6502 CPU simulator. Made by Aleksander Kaminski in 2017.\n");
				usage(argv[0]);
				return 0;

			case 'v':
				printf("AK6502 CPU simulator. Made by Aleksander Kaminski 2017.\n");
				printf("Version: %s\n", VERSION);
				return 0;

			case '?':
				if (optopt == 'o' || optopt == 'f')
					fprintf(stderr, "Option -%c requires an argument.\n", optopt);
				else if (isprint(optopt))
					fprintf(stderr, "Unknown option `-%c'.\n", optopt);
				else
					fprintf (stderr, "Unknown option character `\\x%x'.\n", optopt);
			default:
				usage(argv[0]);
				return -1;
		}
	}

	if (path[0] != '\0') {
		INFO("Initializing RAM from %s file at offset 0x%04x", path, offset);

		if ((rom = malloc(65536)) == NULL)
			FATAL("Out of memory!");

		if (parse_file(path, offset, rom, 65536) < 0) {
			WARN("Could not parse initialization file");
			free(rom);
			rom = NULL;
		}
	}

	if (rom == NULL) {
		FATAL("Memory has not been initialized");
	}

	memory_init(rom);
	free(rom);

	core_init();
	core_setSpeed(freq);

	INFO("Resetting CPU...");
	core_rst();
	INFO("Ready.");

	/* Pocket65 code here */
	pocket65();

	core_getState(NULL, &cycles);
	INFO("Ending simulation. CPU took total of %u cycles.", cycles);

	return 0;
}

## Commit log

2022-07-16 Add Rev. A schematic and Gerber files
    [b.gbl, bs.gbs, opis.gbl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]
2022-07-16 Implement FW system functions, UI, interrupt handling
2022-07-18 Fix various bugs, non testes printd functions
2022-07-19 Improve simulator by calibrating sleeps
2022-07-19 Fixed printx_u16
2022-07-19 Working printd_u16 and printd_s16 functions
2022-07-20 HW: Fix wrong transistors specified. Regerated gerber files (cosmetic change)
    [b.gbl, bs.gbs, opis.gtl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]
2022-07-20 HW: Add PCB mechanical spec
2022-07-20 HW: Add bottom plate/battery holder STL
    [base.FCStd, base.stl]
2022-07-25 Improve printd_u16 - remove leading zeroes before displaying them
2022-07-31 Add BOM
2022-07-31 Replace BOM html with CSV
    [BOM.csv]
2022-07-31 3dprint: Add backcover/battery holder
    [base.FCStd, base.stl, cover.FCStd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]
2022-07-31 3dprint: Reduce back cover thickness
    [cover.FCStd, cover.stl]
2022-08-07 Update BOM and schematic
    - add 1 MHz value to the generator,
    - change default clock clk to 1/2 generator Hz (500 kHz) because of slow EPROMs (450 ns access time, on egde when PH0 is 1 MHz),
    - DNP pull-downs for LED screen (not needed)
    [BOM.csv]
2022-08-28 Add Pocket65 revision B HW files
    [BOM.csv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]
2022-08-28 Add eeprom expansion HW files
    [eeprom.GBL, eeprom.GBO, eeprom.GBP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]
2023-09-17 Remove non-working HW revision
    [BOM.csv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]
